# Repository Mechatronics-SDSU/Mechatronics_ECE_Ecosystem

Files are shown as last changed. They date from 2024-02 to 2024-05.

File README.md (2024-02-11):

# Mechatronics_ECE_Ecosystem
Center for anything that makes lights blink and motors spin.
  
The new revision of a cohesive electrical system to support all Mechatronics projects consisting of several "modules" communicating on shared multi-drop buses. 
Each module consists of:
- Hardware (schematic + PCB)
- Firmware and Build Files
- Fabrication files
  
Each module shall:
- Have a specific and well scoped goal
- Serve to more efficiently distribute processing as a part of the whole system
- Respect the shared communications standards defined in this repository
- Be well researched, tested, and documented

## Repository Structure
- Embedded CAN Bus
    - Contains documentation and libraries for inter-module communications

- Board Support
    - List of supported hardware
    - Contains information on supported MCU/FPGAs
    - Example projects and guides on how to use and implement a specific device

- General Documentation
    - well... it's in the name
    - Overall architectural goals and descriptions of our target system and all current/future needs

- KiCad Libraries
    - KiCad 7 symbols, footprints, and models created for individual modules

## General Hardware Support
A set of selected processors and FPGAs are listed that contain the requisite information to quickly bring any project up. These parts are by no means the only acceptable options, but are provided to reduce the load when starting a project.

Also run linux, it makes all of this so much easier. :)

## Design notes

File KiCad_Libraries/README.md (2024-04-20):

# KiCad Libraries
Currently all files support KiCad 7+

## One might ask, Where should I put my stuff???

This is simple okay... All ya gotta do is 
|footprints --> ./goldmansachs.pretty
symbals    --> ./cymbals
step files --> ./mechanicalshit

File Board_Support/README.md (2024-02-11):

# Board Support
Currently well supported hardware is as follows:
- RP2040 + MCP25625 (CAN Adapter)
- Teensy 4.0, 4.1

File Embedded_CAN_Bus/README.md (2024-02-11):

# Embedded CAN Bus
A shared bus connects all modules on the bus....

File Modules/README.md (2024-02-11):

# Modules
Several modules are required to sustain an effective system.  
A module may be standalone, or represent a subsystem that requires a single point of bus interface (notably Power System Management).
  
To better organize the multiple projects that will be present here another layer of directories are present.
### Acoustics and Communication
- Hydrophone direction finding
- Acoustic data processing / collection
- Optical and Acoustic Communications methods
### Controller
- Main bus controller
- Interface with embedded computers (Jetsons, Pis, etc..)
### Human Interface
- Controls boxes
- Lighting systems
### Motion
- ESC Drivers
- Servo Controllers
- Motion Processing
### Power Systm
- Power conversion (DC-DC, AC-DC)
- Power monitoring
- Battery priority and failover
- Battery charging
- Power path management
### Safety
- Internal system state
- Temperature and leak monitoring
- General system watchdog
### Example
- Template Project

## Completed Modules
  
## Modules In Progress
- Bus Manager / Computer Interface Module
- Human Interface Module
- System Health Monitoring Module
- Motor and Drive Control Module
- RGB Pattern Module
- Power System Management
- Hydrophone Direction Finding
- Acoustic Communications
- A ton of power projects

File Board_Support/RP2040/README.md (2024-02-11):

# RP2040
A very fast dual core processor that's cheap, available, and has good software support.  
  
## Features and Limitations
- No CAN, must use MCP25625 SPI-CAN interface
- 125MHz dual core
- No floating point hardware
- CMake build system
- USB flashing ability
- PIO peripheral is incredibly powerful
  
Trivial setup on linux, annoying on Windows.

## Programming Methods
- USB programming
    - By pulling the QSPI flash chip select line low upon powerup the device will open as a USB Mass Storage Device (like a flash drive), where a user can drag and drop a `.uf2` file (compiled binary) into it. The RP2040 will reboot and execute the loaded code.

- 2 Wire Debug
    - Through the use of openocd/picotool, typically done via picoprog a `.elf` (compiled binary) can be loaded via the SWD pins into the processor

## Toolchain Setup
Linux systems with apt can simply run `pico_setup.sh` provided by the Raspberry Pi Foundation.  
Windows users should follow Shawn Hymel's excellent guide. Use common sense, don't install Python/VSCode twice if you already have it..  
  
- [Pico Setup Shell Script](https://github.com/raspberrypi/pico-setup/blob/master/pico_setup.sh)
- [Shawn Hymel Windows Pico SDK Install Guide](https://shawnhymel.com/2096/how-to-set-up-raspberry-pi-pico-c-c-toolchain-on-windows-with-vs-code/)
  
## Building a Project
A project should be started in its own directory, where the following are contained:
- All source code files
- CMakeLists.txt
- `pico_sdk_import.cmake`
  
Create a directory named `build` in the main project directory and enter the directory.  
On Linux open a terminal and run `cmake ..`  
On Windows open Git Bash in the terminal and run `cmake -G "MinGW Makefiles" ..`  
  
Next on either operating system run `make -j{4-16}`, where `{4-16}` is the maximum number of threads you wish to compile with. `-j4` or `-j8` are good defaults.  
  
The compile and link step will now proceed. If a syntax, linker, or other error are to occur they will happen at this step.  
  
Many issues are caused by a bad CMakeLists.txt file or on Windows not having a correct PATH setup.  

### Build Tips
- Any time a new library is added to a project it's highly likely you must add this to your CMakeLists.txt
- Any time the CMakeLists.txt is modified you must delete your `build` directory, recreate it, and run the appropriate `cmake` command again

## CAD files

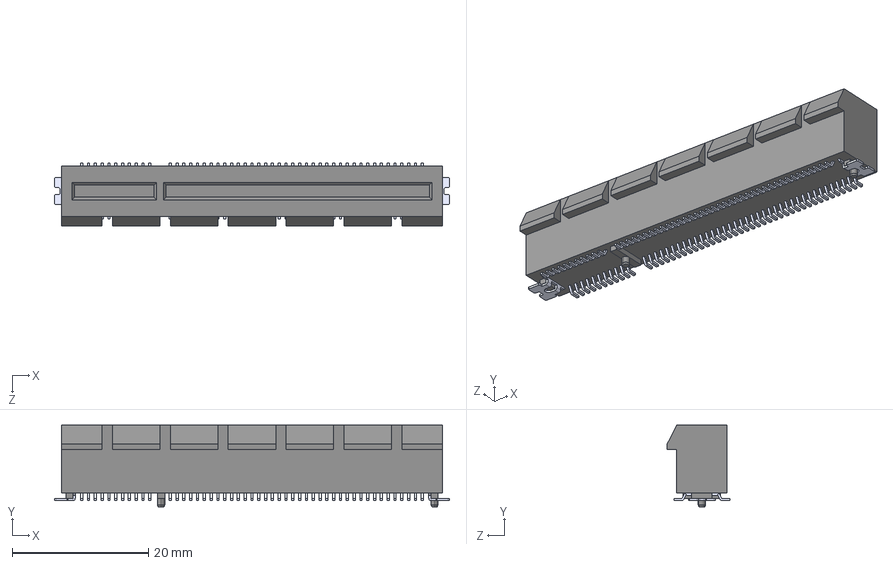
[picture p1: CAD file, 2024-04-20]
KiCad_Libraries/mechanicalshit/10061913-102CLF.step
58.0 x 12.0 x 9.20 mm

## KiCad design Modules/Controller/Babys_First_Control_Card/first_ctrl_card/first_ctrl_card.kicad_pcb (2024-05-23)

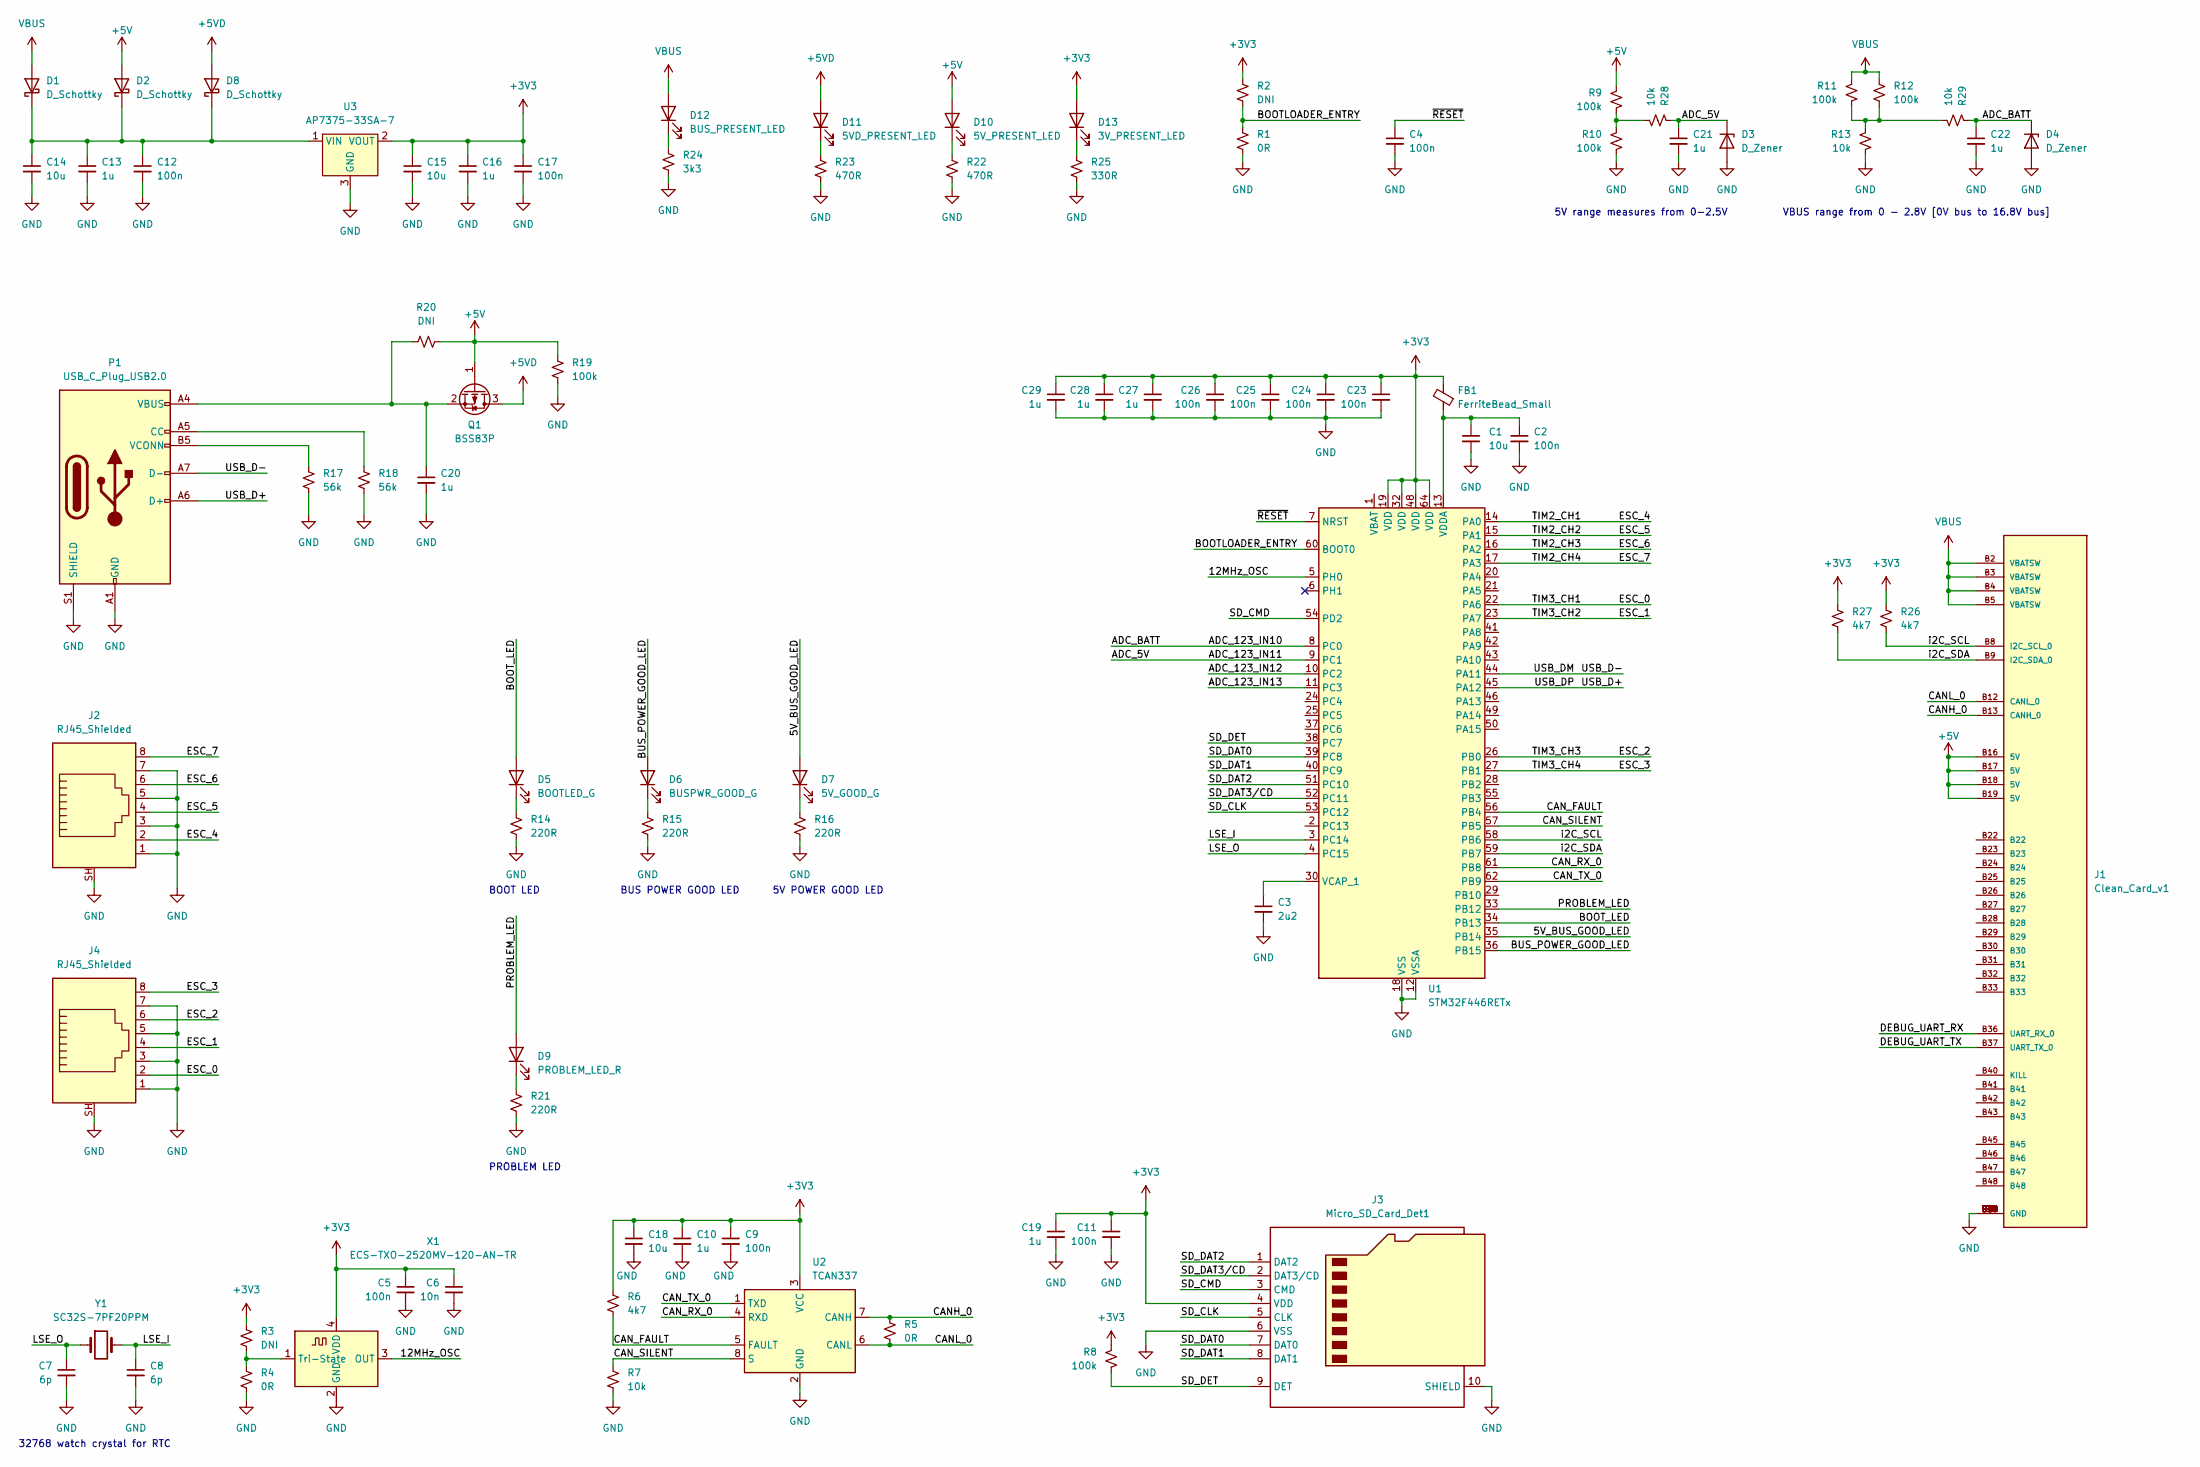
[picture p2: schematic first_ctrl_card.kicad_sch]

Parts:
C1, C14, C15, C18: 10u; C_0805_2012Metric
C2, C4, C5, C9, C11, C12, C17, C23, C24, C25, C26: 100n; C_0805_2012Metric
C3: 2u2; C_0805_2012Metric
C6: 10n; C_0805_2012Metric
C7, C8: 6p; C_0805_2012Metric
C10, C13, C16, C19, C20, C21, C22, C27, C28, C29: 1u; C_0805_2012Metric
D1, D2, D8: D_Schottky; D_SOD-123
D3, D4: D_Zener; D_SOD-123
D5: BOOTLED_G; LED_0805_2012Metric
D6: BUSPWR_GOOD_G; LED_0805_2012Metric
D7: 5V_GOOD_G; LED_0805_2012Metric
D9: PROBLEM_LED_R; LED_0805_2012Metric
D10: 5V_PRESENT_LED; LED_0805_2012Metric
D11: 5VD_PRESENT_LED; LED_0805_2012Metric
D12: BUS_PRESENT_LED; LED_0805_2012Metric
D13: 3V_PRESENT_LED; LED_0805_2012Metric
FB1: FerriteBead_Small; L_0603_1608Metric
J1: Clean_Card_v1; official_mechatronics_card; PARTREV S
J2, J4: RJ45_Shielded; RJ45_Ninigi_GE
J3: Micro_SD_Card_Det1; MSD-1-A_SD_CARD_W_DET
P1: USB_C_Plug_USB2.0; USB_C_Receptacle_GCT_USB4105-xx-A_16P_TopMnt_Horizontal
Q1: BSS83P; SOT-23
R1, R4, R5: 0R; R_0805_2012Metric
R2, R3, R20: DNI; R_0805_2012Metric
R6, R26, R27: 4k7; R_0805_2012Metric
R7, R13, R28, R29: 10k; R_0805_2012Metric
R8, R9, R10, R11, R12, R19: 100k; R_0805_2012Metric
R14, R15, R16, R21: 220R; R_0805_2012Metric
R17, R18: 56k; R_0805_2012Metric
R22, R23: 470R; R_0805_2012Metric
R24: 3k3; R_0805_2012Metric
R25: 330R; R_0805_2012Metric
U1: STM32F446RETx; LQFP-64_10x10mm_P0.5mm
U2: TCAN337; TSOT-23-8
U3: AP7375-33SA-7; SOT-23-3
X1: ECS-TXO-2520MV-120-AN-TR; Oscillator_SMD_ECS_2520MV-xxx-xx-4Pin_2.5x2.0mm
Y1: SC32S-7PF20PPM

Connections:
+3V3: C5.1, C6.1, C9.1, C10.1, C11.1, C15.1, C16.1, C17.1, C18.1, C19.1, C23.1, C24.1, C25.1, C26.1, C27.1, C28.1, C29.1, D13.2 (A), FB1.2, J3.4 (VDD), R2.1, R3.1, R6.1, R8.1, R26.1, R27.1, U1.19 (VDD), U1.32 (VDD), U1.48 (VDD), U1.64 (VDD), U2.3 (VCC), U3.2 (VOUT), X1.4 (VDD)
+5V: D2.2 (A), D10.2 (A), J1.B16 (5V), J1.B17 (5V), J1.B18 (5V), J1.B19 (5V), Q1.1 (G), R9.1, R19.1, R20.2
+5VD: D8.2 (A), D11.2 (A), Q1.3 (D)
/5V_BUS_GOOD_LED: D7.2 (A), U1.35 (PB14)
/12MHz_OSC: U1.5 (PH0), X1.3 (OUT)
/ADC_123_IN10: C22.1, D4.1 (K), R29.1, U1.8 (PC0)
/ADC_123_IN11: C21.1, D3.1 (K), R28.1, U1.9 (PC1)
/ADC_123_IN12: U1.10 (PC2)
/ADC_123_IN13: U1.11 (PC3)
/BOOTLOADER_ENTRY: R1.1, R2.2, U1.60 (BOOT0)
/BOOT_LED: D5.2 (A), U1.34 (PB13)
/BUS_POWER_GOOD_LED: D6.2 (A), U1.36 (PB15)
/CANH_0: J1.B13 (CANH_0), R5.1, U2.7 (CANH)
/CANL_0: J1.B12 (CANL_0), R5.2, U2.6 (CANL)
/CAN_FAULT: R6.2, U1.56 (PB4), U2.5 (FAULT)
/CAN_RX_0: U1.61 (PB8), U2.4 (RXD)
/CAN_SILENT: R7.1, U1.57 (PB5), U2.8 (S)
/CAN_TX_0: U1.62 (PB9), U2.1 (TXD)
/DEBUG_UART_RX: J1.B36 (UART_RX_0)
/DEBUG_UART_TX: J1.B37 (UART_TX_0)
/ESC_0: J4.2, U1.22 (PA6)
/ESC_1: J4.4, U1.23 (PA7)
/ESC_2: J4.6, U1.26 (PB0)
/ESC_3: J4.8, U1.27 (PB1)
/ESC_4: J2.2, U1.14 (PA0)
/ESC_5: J2.4, U1.15 (PA1)
/ESC_6: J2.6, U1.16 (PA2)
/ESC_7: J2.8, U1.17 (PA3)
/LSE_I: C8.1, U1.3 (PC14), Y1.2
/LSE_O: C7.1, U1.4 (PC15), Y1.1
/PROBLEM_LED: D9.2 (A), U1.33 (PB12)
/SD_CLK: J3.5 (CLK), U1.53 (PC12)
/SD_CMD: J3.3 (CMD), U1.54 (PD2)
/SD_DAT0: J3.7 (DAT0), U1.39 (PC8)
/SD_DAT1: J3.8 (DAT1), U1.40 (PC9)
/SD_DAT2: J3.1 (DAT2), U1.51 (PC10)
/SD_DAT3/CD: J3.2 (DAT3/CD), U1.52 (PC11)
/SD_DET: J3.9 (DET), R8.2, U1.38 (PC7)
/USB_D+: P1.A6 (D+), U1.45 (PA12)
/USB_D-: P1.A7 (D-), U1.44 (PA11)
/i2C_SCL: J1.B8 (I2C_SCL_0), R26.2, U1.58 (PB6)
/i2C_SDA: J1.B9 (I2C_SDA_0), R27.2, U1.59 (PB7)
/~RESET: C4.1, U1.7 (NRST)
GND: C1.2, C2.2, C3.2, C4.2, C5.2, C6.2, C7.2, C8.2, C9.2, C10.2, C11.2, C12.2, C13.2, C14.2, C15.2, C16.2, C17.2, C18.2, C19.2, C20.2, C21.2, C22.2, C23.2, C24.2, C25.2, C26.2, C27.2, C28.2, C29.2, D3.2 (A), D4.2 (A), J1.B1 (GND), J1.B6 (GND), J1.B7 (GND), J1.B10 (GND), J1.B11 (GND), J1.B14 (GND), J1.B15 (GND), J1.B20 (GND), J1.B21 (GND), J1.B34 (GND), J1.B35 (GND), J1.B38 (GND), J1.B39 (GND), J1.B44 (GND), J1.B49 (GND), J2.1, J2.3, J2.5, J2.7, J2.SH, J3.6 (VSS), J3.10 (SHIELD), J4.1, J4.3, J4.5, J4.7, J4.SH, P1.A1 (GND), P1.A12 (GND), P1.B1 (GND), P1.B12 (GND), P1.S1 (SHIELD), R1.2, R4.2, R7.2, R10.2, R13.2, R14.2, R15.2, R16.2, R17.2, R18.2, R19.2, R21.2, R22.2, R23.2, R24.2, R25.2, U1.12 (VSSA), U1.18 (VSS), U1.31 (VSS), U1.47 (VSS), U1.63 (VSS), U2.2 (GND), U3.3 (GND), X1.2 (GND)
unnamed: C12.1, C13.1, C14.1, D1.1 (K), D2.1 (K), D8.1 (K), U3.1 (VIN)
unnamed: D5.1 (K), R14.1
unnamed: D6.1 (K), R15.1
unnamed: D7.1 (K), R16.1
unnamed: D9.1 (K), R21.1
unnamed: D10.1 (K), R22.1
unnamed: D11.1 (K), R23.1
unnamed: D12.1 (K), R24.1
unnamed: D13.1 (K), R25.1
unnamed: P1.A5 (CC), R18.1
unnamed: P1.B5 (VCONN), R17.1
unnamed: C20.1, P1.A4 (VBUS), P1.A9 (VBUS), P1.B4 (VBUS), P1.B9 (VBUS), Q1.2 (S), R20.1
unnamed: R9.2, R10.1, R28.2
unnamed: R11.2, R12.2, R13.1, R29.2
unnamed: C3.1, U1.30 (VCAP_1)
unnamed: C1.1, C2.1, FB1.1, U1.13 (VDDA)
unnamed: R3.2, R4.1, X1.1 (Tri-State)
VBUS: D1.2 (A), D12.2 (A), J1.B2 (VBATSW), J1.B3 (VBATSW), J1.B4 (VBATSW), J1.B5 (VBATSW), R11.1, R12.1

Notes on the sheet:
PROBLEM LED
VBUS range from 0 - 2.8V [0V bus to 16.8V bus]
5V POWER GOOD LED
BUS POWER GOOD LED
BOOT LED
5V range measures from 0-2.5V
32768 watch crystal for RTC

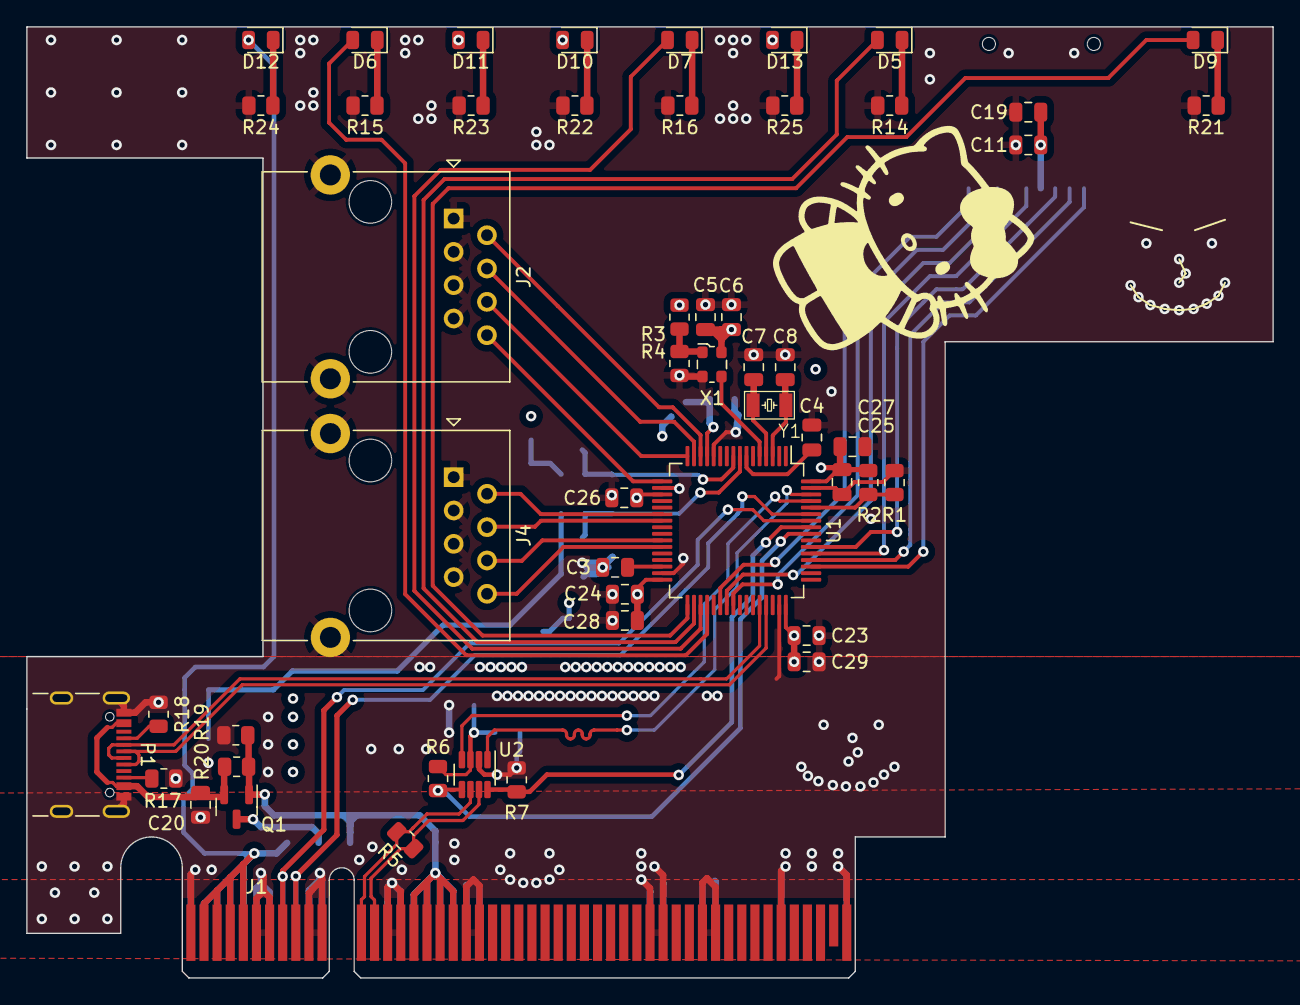
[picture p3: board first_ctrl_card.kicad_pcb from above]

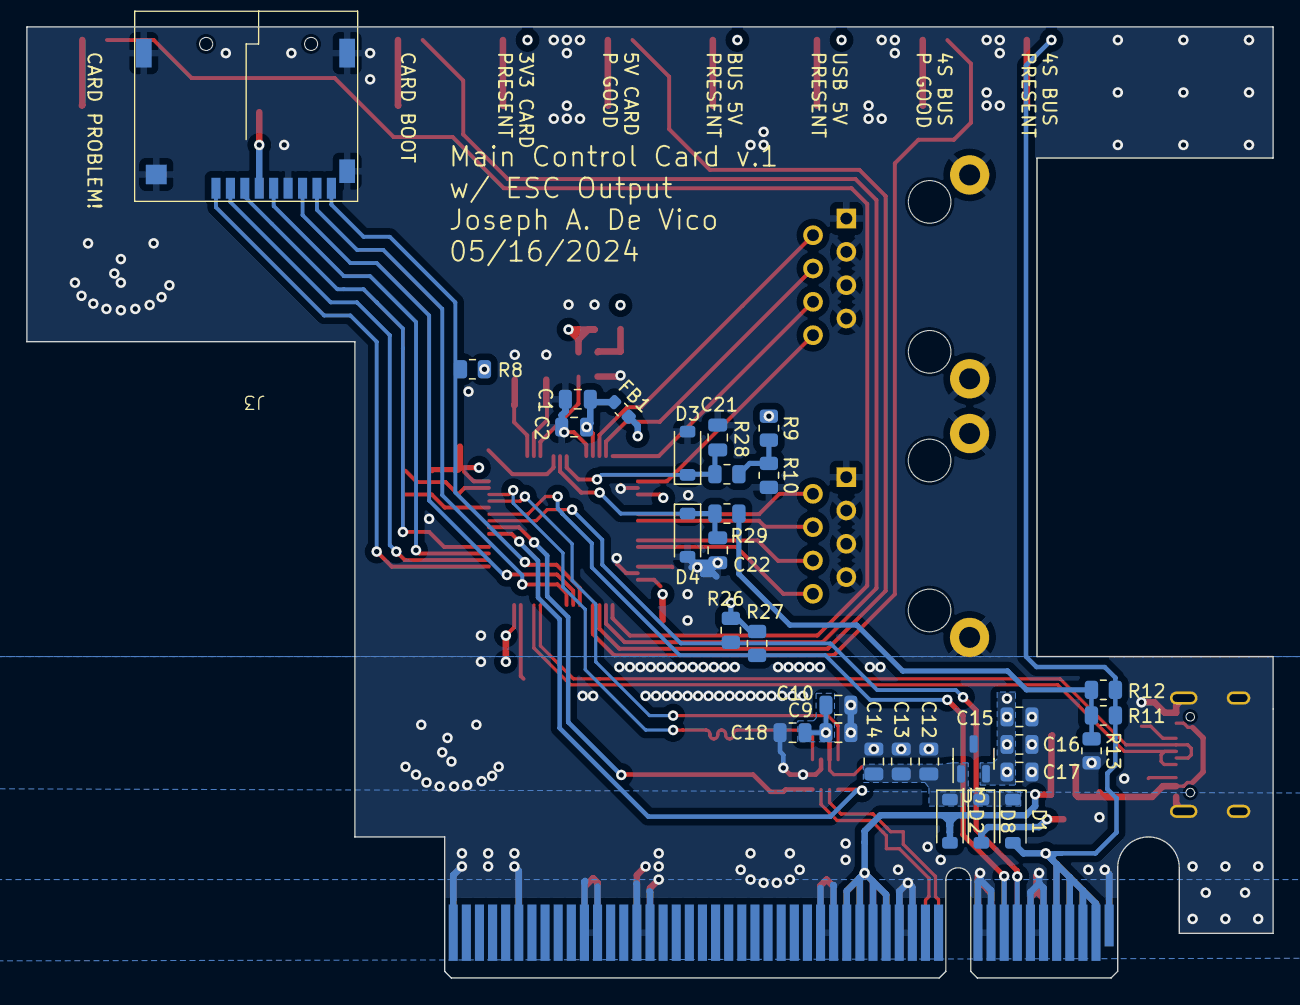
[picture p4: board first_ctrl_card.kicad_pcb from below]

Board: 4 copper layers, 95.0 x 72.5 mm, 83 parts (31 on the bottom side), 58 nets.

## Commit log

2024-04-20 This is not a virus I swear to got please ACCEPT THIS COMMIT IT WILL NOT GIVE YOU RANSOMWEAR THAT WILL COST 15,000 iranian Rial to my Monero Wallet at 0x80019ab0. OK THANK YOU FOR ACCEPRING MY COMMIT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
    [10061913-102CLF.step, The_Plate_V0.kicad_pcb, The_Plate_V0.kicad_sch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]
2024-04-27 This is wa good one Trust bro
    [V1.kicad_pcb, V1.kicad_sch]
2024-04-27 Wee woo example added
    [first_ctrl_card.kicad_pcb, first_ctrl_card.kicad_sch]
2024-04-27 Almost done with card profile
    [first_ctrl_card.kicad_pcb, first_ctrl_card.kicad_sch]
2024-05-10 Control card dump
    [first_ctrl_card.kicad_pcb, first_ctrl_card.kicad_sch]
